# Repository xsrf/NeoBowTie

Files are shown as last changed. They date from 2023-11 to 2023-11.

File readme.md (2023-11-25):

# NeoBowTie



## Features
- Bowtie style PCB
- 17 NeoPixel RGB LEDs (SK6812) facing through the PCB
- Powered by rechargeable LiPo Battery (420mAh)
- Charged via MicroUSB (2h to full charge)
- Custom programming via MicroUSB
- Based on ATTiny85 microcontroller
- Mode/Animation selection via Button

## Operation

A **short press** on the MODE button cycles the available modes. When you **hold down** the MODE button, the current animations slows down or changes its style each time the center LED flashes.

When powered up, it briefly shows a battery indication with green and red LEDs. But since a 3.3V LDO is used, it will only start showing red LEDs once the battery voltage drops below 3.3V. All red means 2.7V and the device will turn off to protect the battery.

The **first mode after power-up** can be used to adjust the brightness. **hold down** the MODE button to gradually lower the brightness in 16 steps.

## Getting started (programming)

### Installing VSCode and PlatformIO
Install [VSCode](https://code.visualstudio.com/) and open the downloaded/cloned [project folder](https://github.com/xsrf/NeoTree/archive/refs/heads/master.zip) in VScode.
VSCode should ask you to install the PlatformIO extension - do so.
You may need to close VSCode and open the folder once again in VSCode for PlatformIO to recognize the project.
Open `src/main.c` and look for "Build", "Upload", "Home" buttons on the bottom bar of VSCode.

### Installing Zadig (Windows)
Download Zadig from [here](https://zadig.akeo.ie/) or [github releases](https://github.com/pbatard/libwdi/releases). 
Zadig is used to install the required USB driver. See the [documentation](https://github.com/pbatard/libwdi/wiki/Zadig) for more details and screenshots.
Assign the `libusb-win32` driver (not `winusb`).

To do so, the NeoBowTie needs to be pre-flashed with the USB bootloader (it is if you got it from me, otherwise see *usb-bootloader* subfolder), turned off, connected via MicroUSB cable and then turned on. It should appear in Zadig. Select "Options - List All Devices" if it doesn't. Select `libusb-win32` and click install.

### Compile and upload code
Open the project folder in VSCode and open `src/main.c`. Make sure to select `env:usb` in the bottom bar of VSCode as PlatformIO environment.
Connect the NeoBowTie via USB but keep it turned off.
Then hit upload ("->" Button) and follow the console output.
When it says `Please plug in the device (will time out in 60 seconds) ...` turn on the NeoBowTie. It should immediately upload the new code.
Avoid using USB-Hubs if you have problems with USB detecting the device.

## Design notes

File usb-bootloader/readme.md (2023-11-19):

# Burn USB Bootloader and Fuses
[Micronucleus](https://github.com/micronucleus/micronucleus) is a bootloader designed for AVR ATtiny microcontrollers with a minimal usb interface.
This needs to be flashed once via ICSP. After that, the NeoTree can be flashed with new firmware via USB.
You'll need an ICSP programmer for that.
```
avrdude.exe -c usbasp -B4 -p t85 -v -U flash:w:t85_usbdemo.hex
avrdude.exe -c usbasp -B4 -p t85 -v -U lfuse:w:0xe1:m -U hfuse:w:0xde:m -U efuse:w:0xfe:m
```
See [here](https://eleccelerator.com/fusecalc/fusecalc.php?chip=attiny85&LOW=E1&HIGH=DE&EXTENDED=FE) for fuse description.

## Files
| File | Description |
|---|---|
| backup_attiny85.bat | Reads and backups the contents of the flash |
| flash_attiny85_usbdemo.bat | Flash USB bootloader and Demo program (recommended) |
| flash_attiny85_usbonly.bat | Flash USB bootloader |
| t85_default.hex | Standard micronucelos bootloader |
| t85_fastexit.hex | Micronucelos bootloader which only waits few milliseconds |
| t85_usbdemo.hex | Fastexit micronucelos bootloader and NeoPixel Demo |

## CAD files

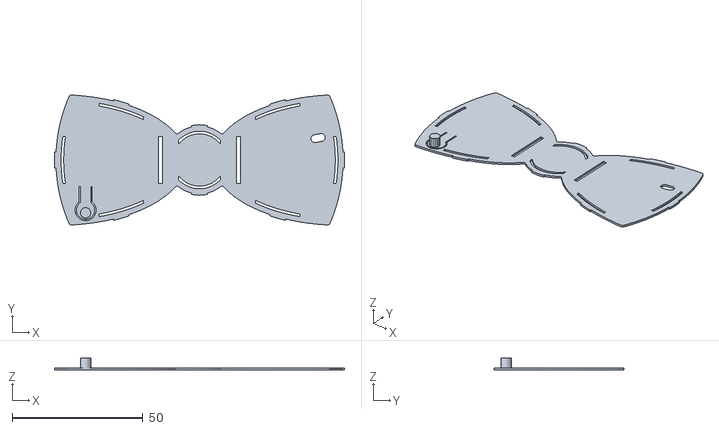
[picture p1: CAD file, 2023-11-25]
3d/bowtie_back_pcb.stl
111.0 x 49.7 x 4.50

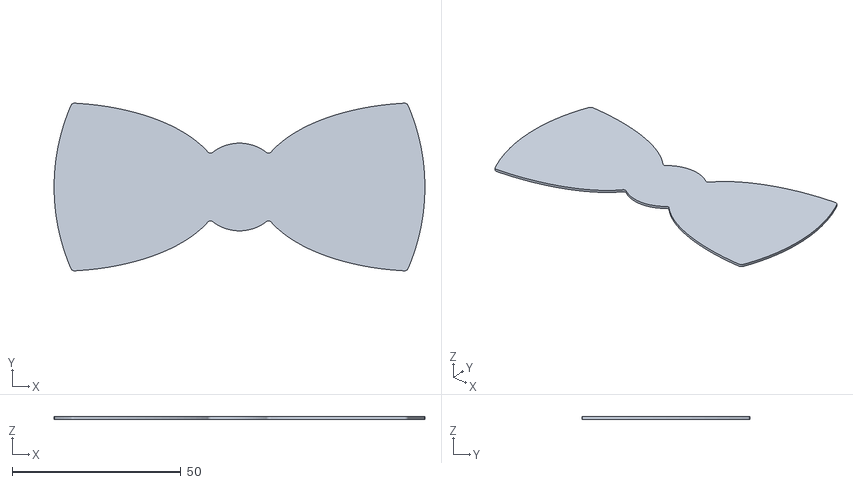
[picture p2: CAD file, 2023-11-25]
3d/bowtie_diffusor_0.75mm.stl
110.0 x 49.7 x 0.75

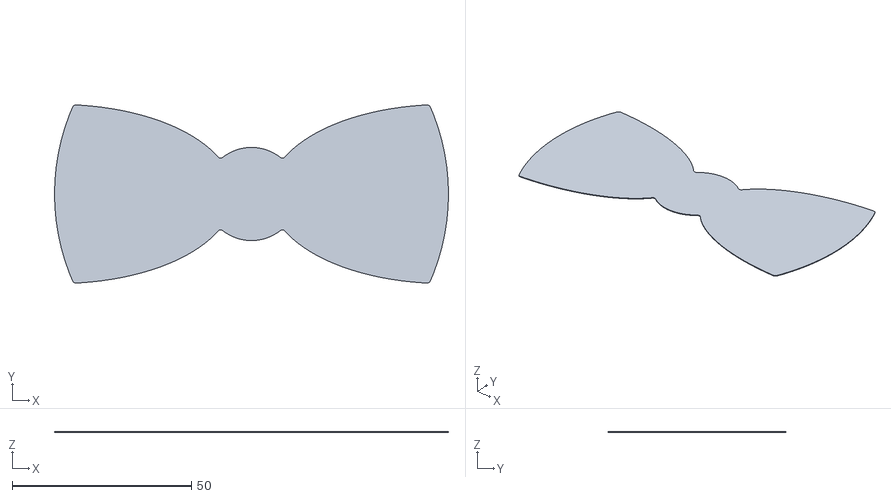
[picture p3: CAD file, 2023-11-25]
3d/bowtie_diffusor_0.2mm.stl
110.0 x 49.7 x 0.2

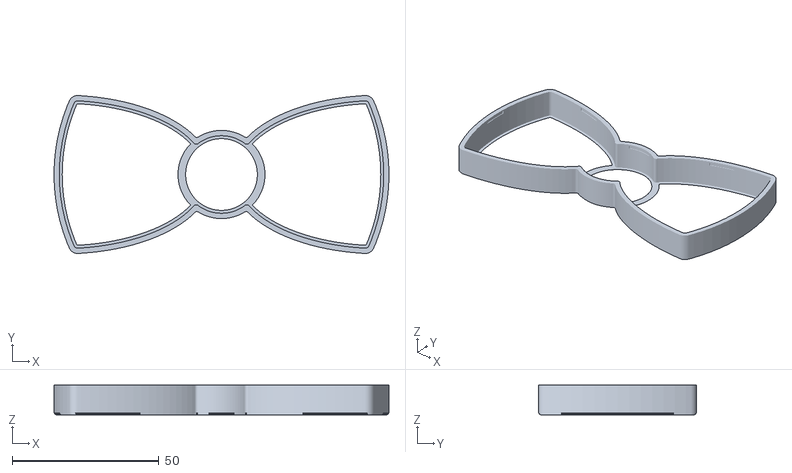
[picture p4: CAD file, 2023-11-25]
3d/bowtie_frame.stl
114.0 x 53.7 x 10.2

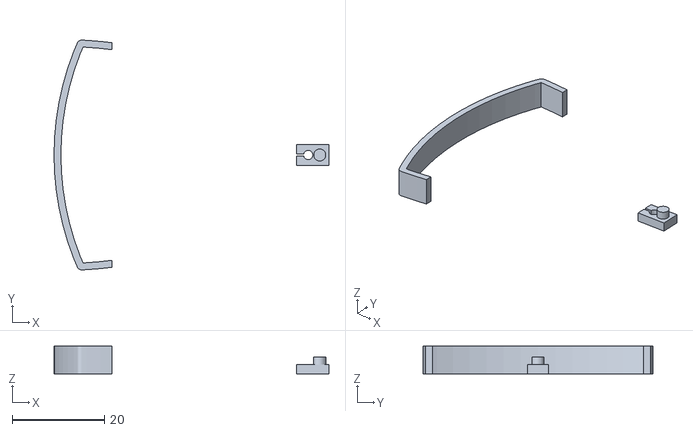
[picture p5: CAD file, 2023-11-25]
3d/bowtie_pcb_stuff.stl
59.5 x 49.7 x 6.00

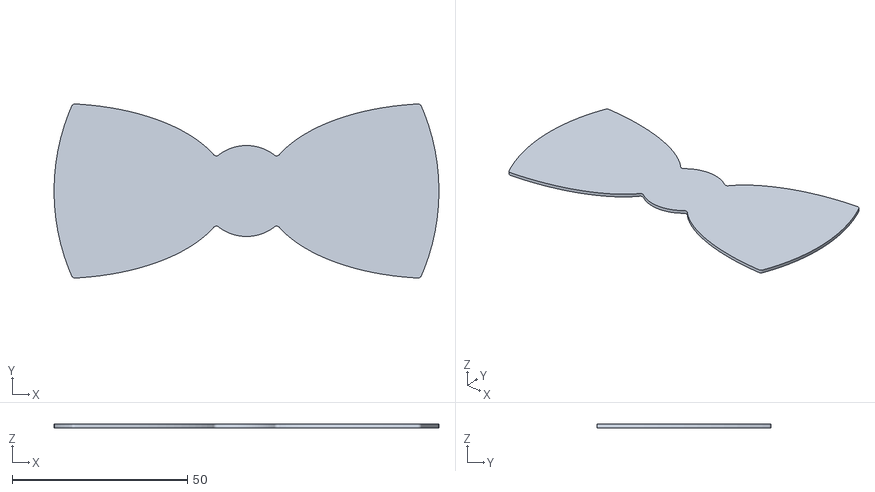
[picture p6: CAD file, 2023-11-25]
3d/bowtie_diffusor_1.0mm.stl
110.0 x 49.7 x 1.00

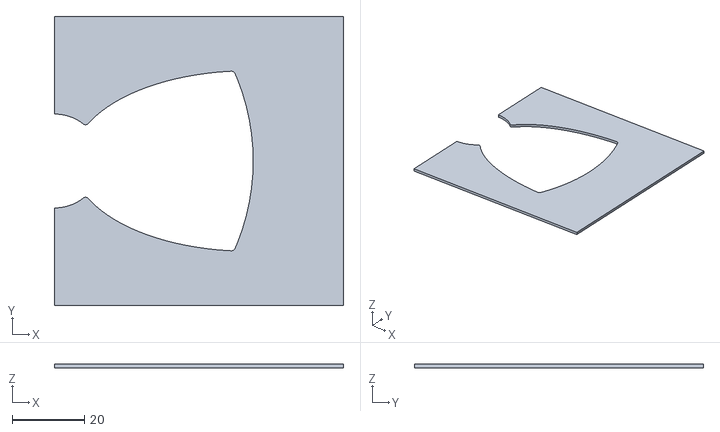
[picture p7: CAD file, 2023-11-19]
3d/bowtie_stencil_jig.stl
80.0 x 80.0 x 1.00

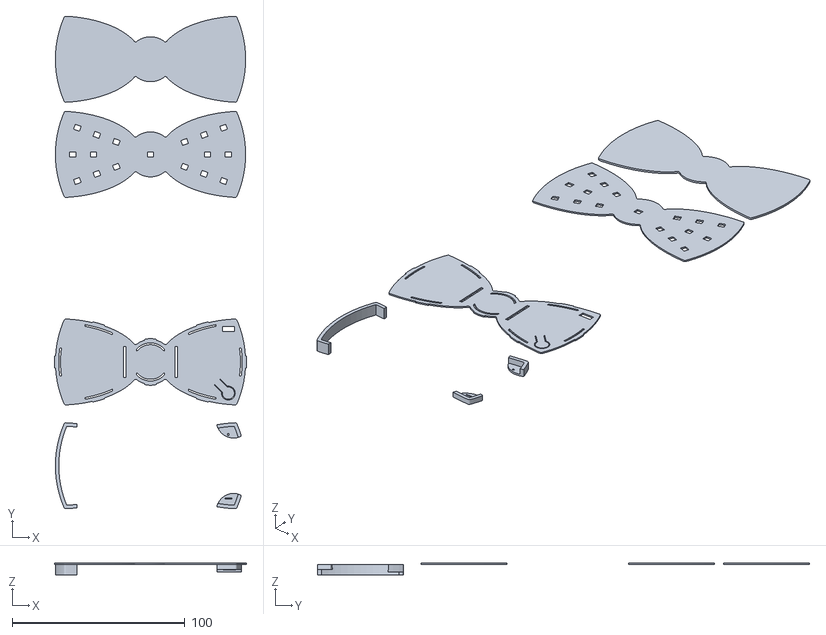
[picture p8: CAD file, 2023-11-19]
3d/bowtie_posts.stl
111.0 x 284.7 x 7.20

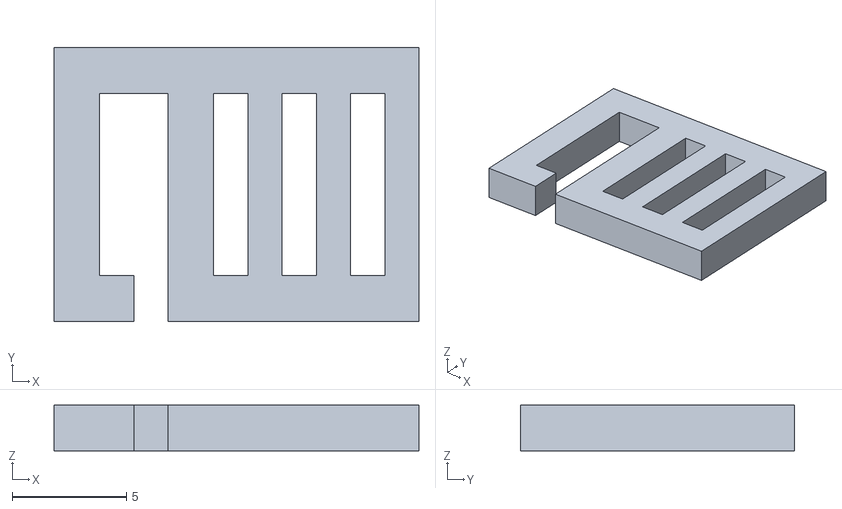
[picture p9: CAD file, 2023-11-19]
3d/bowtie_clip.stl
16.0 x 12.0 x 2.00

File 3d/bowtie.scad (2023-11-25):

$fn=100;

$layer = "";
$dh = 1;

// 2.8 x 3.2 x 1.8


// BowTie with LEDholes (for manual soldering)
if(!$layer || $layer=="led_frame") linear_extrude(0.8) difference() {
    offset(r=-1) offset(r=2) bowtie(1.2);
    led_cutouts();
    mirror([1,0]) led_cutouts();
}

// BowTie diffusor
if(!$layer || $layer=="diffusor") translate([0,55,0]) linear_extrude($dh) offset(r=-1) offset(r=2) bowtie(1.2);


// BowTie frame
if(!$layer || $layer=="frame") translate([0,-60,0]) difference() {
    $h = 9.5+0.7;
    union() {
        translate([0,0,0.6]) linear_extrude($h-0.6) bowtie_outline(1.2);
        translate([0,0,0.0]) linear_extrude(0.2) offset(r=-0.6) bowtie_outline(1.2);
        translate([0,0,0.2]) linear_extrude(0.2) offset(r=-0.4) bowtie_outline(1.2);
        translate([0,0,0.4]) linear_extrude(0.2) offset(r=-0.2) bowtie_outline(1.2);
    }
    translate([0,0,0.5]) linear_extrude($h) offset(r=-1) offset(r=2.2) bowtie(1.2);
    translate([0,0,$h-1-0.5]) linear_extrude(1) intersection() {
        offset(r=-1) offset(r=2.2+0.25) bowtie(1.2);
        union() {
            square([9,100],center=true);
            translate([+30,0]) square([9,100],center=true);
            translate([-30,0]) square([9,100],center=true);
            square([200,9],center=true);
        }
    }
}

// BowTie Back Prototype
if($layer=="back_proto") translate([0,-120,0]) linear_extrude(0.75) 
difference() {       
    union() {
        offset(r=-1) offset(r=2) bowtie(1.2);
        intersection() {
            offset(r=-1) offset(r=2.2+0.3) bowtie(1.2);
            union() {
                square([7,100],center=true);
                square([200,7],center=true);
                translate([-30,0]) square([7,100],center=true);
                translate([+30,0]) square([7,100],center=true);
            }
        }
    }
    intersection() {
        difference() {
            offset(r=-1) bowtie(1.2);
            offset(r=-2) bowtie(1.2);
        }
        union() {
            square([16,100],center=true);
            translate([+100+14,0,0]) square([200,16],center=true);
            translate([-100-14,0,0]) square([200,16],center=true);
            translate([+30,0]) square([16,100],center=true);
            translate([-30,0]) square([16,100],center=true);
        }
    }
    translate([+15,0]) square([1.5,18],center=true);
    translate([-15,0]) square([1.5,18],center=true);
    translate([45,19]) square([7,3],center=true);
    //translate([45,19]) square([9,8],center=true);
    translate([45,-18]) rotate(45) button_cutout();
}

// BowTie Back PCB
if(!$layer || $layer=="back_pcb") translate([0,-120,0]) { 
    linear_extrude(0.75) difference() {       
        union() {
            offset(r=-1) offset(r=2) bowtie(1.2);
            intersection() {
                offset(r=-1) offset(r=2.2+0.3) bowtie(1.2);
                union() {
                    square([6,100],center=true);
                    square([200,6],center=true);
                    translate([-30,0]) square([6,100],center=true);
                    translate([+30,0]) square([6,100],center=true);
                }
            }
        }
        intersection() {
            difference() {
                offset(r=-1) bowtie(1.2);
                offset(r=-2) bowtie(1.2);
            }
            union() {
                square([16,100],center=true);
                translate([+100+14,0,0]) square([200,18],center=true);
                translate([-100-14,0,0]) square([200,18],center=true);
                translate([+30,0]) square([17,100],center=true);
                translate([-30,0]) square([17,100],center=true);
            }
        }
        translate([+15,0]) square([1.5,18],center=true);
        translate([-15,0]) square([1.5,18],center=true);
        translate([-43.6,-20.2+1]) button_cutout();
        // Switch Cutout
        //translate([47.9,8.4]) rotate(10) square([9,5],center=true);
        translate([47.9-2.5,8.4]) rotate(10) hull() {
            translate([+1.25,0,0]) circle(r=1.5);
            translate([-1.25,0,0]) circle(r=1.5);
        }
    }
    // Button post
    translate([-43.6,-20.2]) cylinder(r=2,h=4.5,$fn=16);
}


if($layer=="proto_stuff") translate([0,-180,0]) rotate([180,0,0]){
    switch_post();
    button_post();
    side_post();
}

if(!$layer || $layer=="pcb_stuff") translate([0,-180,0]) {
    switch_know();
    side_post_pcb();
}

module bowtie(s=1) scale(s) {
    circle(r=10);
    translate([45,0]) intersection() {
        scale([2,1]) circle(r=20);
        translate([-50,0]) circle(r=50);
    }
    mirror([1,0])translate([45,0]) intersection() {
        scale([2,1]) circle(r=20);
        translate([-50,0]) circle(r=50);
    }    
}

module led_cutout() {
    square([3.6,3.0],center=true);
}

module led_cutouts() {
    led_cutout();
    for(i=[-20,0,20]) rotate(i) translate([45,0]) led_cutout();
    for(i=[-20,0,20]) rotate(i) translate([33,0]) led_cutout();
    for(i=[-20,20]) rotate(i) translate([21,0]) led_cutout();
}

module bowtie_outline(s=1) {
    difference() {
        offset(r=-1) offset(r=4) bowtie(s);
        difference() {
            bowtie(s);
            offset(r=3) circle(r=10*s);
        }
        offset(r=3) circle(r=7.5*s);
    }
}

module bowtie_outlineX(s=1) union() {
    difference() {
        offset(r=-1) offset(r=4) bowtie(s);
        offset(r=0) bowtie(s);
        //offset(r=-0.8) offset(r=2) bowtie(1.2);
    }
    difference() {
        offset(r=3) circle(r=10*s);
        offset(r=3) circle(r=7.5*s);
    }
}


module button_cutout() {
    difference() {
        union() {
            circle(r=4);
            translate([0,5]) square([5,8],center=true);
        }
        circle(r=3.5);
        translate([0,5]) square([4,10],center=true);
    }
}



module switch_post() {
    $h = 8-1.8-3.4; // Elevation
    intersection() {
        difference() {
            linear_extrude($h) offset(r=-1) offset(r=2) bowtie(1.2);
            linear_extrude($h-1) offset(r=-1) bowtie(1.2);
            translate([45,19]) cube([4,0.5,20],center=true);
        }
        translate([48,26,0]) cylinder(r=10,h=10,$fn=32);
    }
}

module button_post() {
    $h = 8-1.8-2; // Elevation
    intersection() {
        difference() {
            linear_extrude($h) offset(r=-1) offset(r=2) bowtie(1.2);
            linear_extrude($h-1) offset(r=-1) bowtie(1.2);
            translate([45,-18]) cube([1,1,20],center=true);
        }
        translate([48,-26,0]) cylinder(r=10,h=10,$fn=32);
    }
}


module side_post() {
    $h = 8-1.8; // Elevation
    intersection() {
        difference() {
            linear_extrude($h) offset(r=-1) offset(r=2) bowtie(1.2);
            linear_extrude($h) offset(r=-1) bowtie(1.2);
        }
        translate([-50,0,0]) cube([15,50,20],center=true);
    }
}

module side_post_pcb() {
    $h = 8-2; // Elevation
    intersection() {
        difference() {
            linear_extrude($h) offset(r=-1) offset(r=2) bowtie(1.2);
            linear_extrude($h) offset(r=-0.5) bowtie(1.2);
        }
        translate([-50,0,0]) cube([15,50,20],center=true);
    }
}

module switch_know() {
    // 8.2mm for diffusor, pcb, space and bottom of lid
    // diff+pcb+switch: 5.6mm
    // 2.6mm below lid
    difference() {
        union() {
            translate([2.5,0,0])cylinder(r=1.3,h=2.6+0.75+0.3,$fn=32);
            translate([1,0,2/2])cube([7,4.5,2],center=true);
        }
        #cylinder(r=1,h=4,$fn=32);
        #translate([-2,0,2])cube([4,0.5,4],center=true);
    }
}

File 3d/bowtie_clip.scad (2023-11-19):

difference() {
    cube([16,12,2]);
    translate([2,2,0]) cube([3,8,4]);
    translate([3.5,0,0]) cube([1.5,8,4]);
    translate([7,2,0]) cube([1.5,8,4]);
    translate([10,2,0]) cube([1.5,8,4]);
    translate([13,2,0]) cube([1.5,8,4]);
}

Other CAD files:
3d/bowtie_pcb.scad
3d/bowtie_stencil_jig.scad

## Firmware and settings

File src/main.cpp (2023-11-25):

/*
  NeoTree
  -------

  Want to program via USB? Make sure to select "env:usb" as PlatformIO environment on the bottom!

*/


#include <Arduino.h>
#include <Adafruit_NeoPixel.h>


const uint8_t LED_PIN = PB0; // works!
const uint8_t BTN = PB1; // BTN to GND ... PB2 on proto, PB1 on PCB
const uint8_t NUM_LEDS = 17;
const uint8_t LONG_PRESS_CNT = 20;
const uint8_t STATUS_LED = 8;

const uint8_t LED_ROW[NUM_LEDS] = { 0,3,5,6,4,1,2,7,8,14,9,10,12,15,16,13,11 };
const uint8_t LED_POSX[NUM_LEDS] = { 
  128-48, // 1
  128-35, // 2
  128-22, // 3
  128-51, // 4
  128-37, // 5
  128-48, // 6
  128-35, // 7
  128-22, // 8
  128, // 9 x
  128+22, // 10
  128+35, // 11
  128+48, // 12
  128+37, // 13
  128+51, // 14
  128+22, // 15
  128+35, // 16
  128+48, // 17
}; // X-Coordinate of LED, centered around 128
const uint8_t LED_POSY[NUM_LEDS] = { 
  128-17, // 1
  128-13, // 2
  128-8, // 3
  128, // 4
  128, // 5
  128+17, // 6
  128+13, // 7
  128+8, // 8
  128, // 9 x
  128+8, // 10
  128+13, // 11
  128+17, // 12
  128, // 13
  128, // 14
  128-8, // 15
  128-13, // 16
  128-17, // 17
}; // Y-Coordinate of LED, centered around 128

unsigned long BTN_PRESS_CNT,GLOBAL_CNT;
byte MODE,SUBMODE = 0;


//const uint8_t LED_PIN = PB1; // Builtin-LED; red is yellow?!
//const uint8_t LED_PIN = PB2; // works!
//const uint8_t LED_PIN = PB3; // works! USB D-; LED white at start
//const uint8_t LED_PIN = PB4; // works! USB D+; LED white at start
//const uint8_t LED_PIN = PB5; // DOES NOT WORK!

Adafruit_NeoPixel strip = Adafruit_NeoPixel(NUM_LEDS, LED_PIN, NEO_GRB + NEO_KHZ800);

uint8_t getRandomPixel();
uint16_t getRandomInt(uint16_t max);
uint32_t fadeBlack(uint32_t color);

/*
    ### ANIMATIONS ###
*/

void ani_rainbow(uint8_t mul = 1) {
  static float offset;
  offset = offset + 4.0/(SUBMODE+1);
  uint8_t offs = round(offset);
  for(uint8_t i=0; i<NUM_LEDS; i++) strip.setPixelColor(LED_ROW[i], strip.ColorHSV((offs+mul*i*(256/NUM_LEDS))<<8,255,255));
}

void ani_solid_color() {
  for(uint8_t i=0; i<NUM_LEDS; i++) strip.setPixelColor(i, strip.ColorHSV(((SUBMODE*20)%256)<<8,255,255));
}

void white_sparkles_rand() {
  for(uint8_t i=0; i<NUM_LEDS; i++) {
    if(getRandomInt(SUBMODE+3)==0 && strip.getPixelColor(i)== strip.Color(0, 0, 0) ) {
      strip.setPixelColor(i, strip.Color(255, 255, 255));
    } else {
      strip.setPixelColor(i, strip.Color(0, 0, 0));
    }
  }
}

void white_sparkles_fade() {
  for(uint8_t i=0; i<NUM_LEDS; i++) {
    if(getRandomInt(SUBMODE+3)==0 && strip.getPixelColor(i)== strip.Color(0, 0, 0) ) {
      strip.setPixelColor(i, strip.Color(255, 255, 255));
    } else {
      strip.setPixelColor(i, fadeBlack(strip.getPixelColor(i)));      
    }
  }
}

void golden_sparkles_fade() {
  for(uint8_t i=0; i<NUM_LEDS; i++) {
    if(getRandomInt(SUBMODE+3)==0 && strip.getPixelColor(i)== strip.Color(0, 0, 0) ) {
      strip.setPixelColor(i, strip.Color(255, 160, 0));
    } else {
      strip.setPixelColor(i, fadeBlack(strip.getPixelColor(i)));      
    }
  }
}

void random_colors() {
  if((GLOBAL_CNT % (2 + SUBMODE)) == 0) {
    strip.setPixelColor( getRandomPixel() , strip.ColorHSV(getRandomInt(255)<<8,255,255) );
  }
}

void dimm() {
  if(SUBMODE>17) SUBMODE = 0;
  if(SUBMODE>0) strip.setBrightness(16-(SUBMODE-1));
  for(uint8_t i=0; i<NUM_LEDS; i++) strip.setPixelColor(i, strip.Color(0, 0, 0));
  strip.setPixelColor(STATUS_LED, strip.Color(255, 255, 255));
  strip.setPixelColor(LED_ROW[0], strip.Color(255, 255, 255));
  strip.setPixelColor(LED_ROW[1], strip.Color(255, 255, 255));
  strip.setPixelColor(LED_ROW[2], strip.Color(255, 255, 255));
  strip.setPixelColor(LED_ROW[NUM_LEDS-1-0], strip.Color(255, 255, 255));
  strip.setPixelColor(LED_ROW[NUM_LEDS-1-1], strip.Color(255, 255, 255));
  strip.setPixelColor(LED_ROW[NUM_LEDS-1-2], strip.Color(255, 255, 255));
}

void off() {
  for(uint8_t i=0; i<NUM_LEDS; i++) strip.setPixelColor(i, strip.Color(0, 0, 0));
  strip.setPixelColor(STATUS_LED, strip.Color(31, 31, 31));
}

void rainbow_x(int spread = 1) {
  static float offset;
  offset = offset + 4.0/(SUBMODE+1);
  uint8_t offs = round(offset);
  for(uint8_t i=0; i<NUM_LEDS; i++) {
    strip.setPixelColor(i, strip.ColorHSV((( LED_POSX[i]+offs )%256)<<8,255,255));
  }
}

/*
    ### OTHER STUFF ###
*/

uint8_t getRandomPixel() {
  return floor( rand()/(RAND_MAX/(NUM_LEDS-1)) );
}

uint16_t getRandomInt(uint16_t max) {
  return floor( rand()/(RAND_MAX/(max+1)) );
}

uint32_t fadeBlack(uint32_t color) {
  return ( color >> 1) & 0x7F7F7F7F;
}

long readVcc() {
  // Read 1.1V reference against AVcc
  // set the reference to Vcc and the measurement to the internal 1.1V reference
  #if defined(__AVR_ATmega32U4__) || defined(__AVR_ATmega1280__) || defined(__AVR_ATmega2560__)
    ADMUX = _BV(REFS0) | _BV(MUX4) | _BV(MUX3) | _BV(MUX2) | _BV(MUX1);
  #elif defined (__AVR_ATtiny24__) || defined(__AVR_ATtiny44__) || defined(__AVR_ATtiny84__)
    ADMUX = _BV(MUX5) | _BV(MUX0);
  #elif defined (__AVR_ATtiny25__) || defined(__AVR_ATtiny45__) || defined(__AVR_ATtiny85__)
    ADMUX = _BV(MUX3) | _BV(MUX2);
  #else
    ADMUX = _BV(REFS0) | _BV(MUX3) | _BV(MUX2) | _BV(MUX1);
  #endif   
  delay(2); // Wait for Vref to settle
  ADCSRA |= _BV(ADSC); // Start conversion
  while (bit_is_set(ADCSRA,ADSC)); // measuring 
  uint8_t low  = ADCL; // must read ADCL first - it then locks ADCH  
  uint8_t high = ADCH; // unlocks both 
  long result = (high<<8) | low; 
  result = 1125300L / result; // Calculate Vcc (in mV); 1125300 = 1.1*1023*1000
  return result; // Vcc in millivolts
}

void showChargingLevel() {
  long vcc = readVcc(); // Vcc in millivolts
  const long min = 2700;
  const long max = 3300; // 3.3V on PCB Version, 4.2V on Prototype
  if(vcc >= min) {
    vcc = vcc - min; // 2700-3300 -> 0-600
    vcc = vcc*NUM_LEDS; 
    vcc = vcc/(max-min); // 0-17
    if(vcc > NUM_LEDS) vcc = NUM_LEDS; // clamp to NUM_LEDS
  } else {
    vcc = 0;
  }
  for(uint8_t i=0; i<NUM_LEDS; i++) strip.setPixelColor(i, strip.Color(50, 0, 0)); // all red
  for(uint8_t i=0; i<vcc; i++) strip.setPixelColor(i, strip.Color(0, 50, 0)); // vcc amount green leds
  strip.show(); 
}

void btnCheck() {
  // Check Button press
  if(digitalRead(BTN) == 0) {
    strip.setPixelColor(STATUS_LED, strip.Color(10, 10, 10));
    BTN_PRESS_CNT++;
    if(BTN_PRESS_CNT%LONG_PRESS_CNT == 0) {
      // Long press action every ~second
      SUBMODE++;
      strip.setPixelColor(STATUS_LED, strip.Color(255, 255, 255));
    }
  } else {
    if(BTN_PRESS_CNT > 1 && BTN_PRESS_CNT < LONG_PRESS_CNT) {
      // Single press action
      MODE++;
      SUBMODE = 0; // reset Sub-Mode when changing to next mode/animation
      GLOBAL_CNT = 0;
      strip.setPixelColor(STATUS_LED, strip.Color(255, 255, 255));
    }
    BTN_PRESS_CNT = 0;
  }
}

void setup() {
  // put your setup code here, to run once:
  cli(); // Disable interrupts
  //CLKPR = (1<<CLKPCE); // Prescaler enable
  //CLKPR = 0x00; // Clock division factor 8 (0011)
  sei(); // Enable interrupts
  //delay(1e3);
  pinMode(BTN,INPUT_PULLUP);
  strip.begin();
  strip.setBrightness(16);
  if(digitalRead(BTN) == 0) strip.setBrightness(32);
  strip.show(); // Initialize all pixels to 'off'
  for(uint8_t i=0; i<NUM_LEDS; i++) strip.setPixelColor(i, strip.Color(30, 30, 30)); strip.show(); delay(500);  // all white - pixel test
  for(uint8_t i=0; i<NUM_LEDS; i++) strip.setPixelColor(i, strip.Color(0, 0, 0)); strip.show(); delay(50); // all off
  showChargingLevel();
  delay(1000);
}


void loop() {
  switch (MODE) {
    case __COUNTER__: dimm(); break;
    case __COUNTER__: off(); break;
    case __COUNTER__: rainbow_x(); break;
    case __COUNTER__: ani_rainbow(0); break;
    case __COUNTER__: ani_rainbow(); break;
    case __COUNTER__: ani_rainbow(7); break;
    case __COUNTER__: ani_solid_color(); break;
    case __COUNTER__: white_sparkles_fade(); break;
    case __COUNTER__: golden_sparkles_fade(); break;
    case __COUNTER__: random_colors(); break;
    default: MODE = 0; break;
  }  
  GLOBAL_CNT++; // global frame count, used for some animations
  btnCheck();
  strip.show(); 
  delay(33); // ~30fps
}

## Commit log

2023-11-25 adapt for voltage behind 3V3 LDO
2023-11-25 update 3D objects
    [bowtie.scad, bowtie_back_pcb.stl, bowtie_diffusor_0.2mm.stl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]
